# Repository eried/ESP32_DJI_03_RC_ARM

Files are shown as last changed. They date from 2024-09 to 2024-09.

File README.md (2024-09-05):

# ESP32 Arm DJI O3

Code from [here](https://github.com/ramiss/arduino_DJI_03_RC_ARM), this is just slightly adapted for my hardware. This allows enabling the full power on the O3 so you can use it for long range planes or cars. I though with the latest firmware was OK to override via the menu, but without arming it, the power is never the maximum the Air unit can deliver.



## What I am using

There is some minor details mising, like the gopro mount. But that is a personal preference. My idea is just to hook the whole video system to something when I want to drive them.

| Part | Comments |
|---|---|
| [DJI O3 Air Unit](https://s.click.aliexpress.com/e/_DFMCnNp) | The camera
| [1800 mAh Original DJI Goggles 2 Battery](https://www.aliexpress.com/item/1005007042116539.html) | Power bank|
| [Alloy Waterproof Case](https://s.click.aliexpress.com/e/_DlB1UcT) | Enclosure for camera|
| [ESP32 30Pin-Type-C](https://s.click.aliexpress.com/e/_DmRukHz) | Microcontroller board, you have to desolder the pins |
| [JST 6P 1.25 extension](https://s.click.aliexpress.com/e/_DeUX0MT) | For connecting to the case connector |
| [JST 2P 2mm for the battery](https://s.click.aliexpress.com/e/_DC9pJQ7) | Can be any connector/cable |
| [USB-C to barrel](https://s.click.aliexpress.com/e/_DDsXURt) | To connect battery as usb-c |
| [Small switch 3mm handle](https://s.click.aliexpress.com/e/_DlFpkBD) | To enable the Arming |
| Heat shrink, super glue and tape | |
| 33 kOhm and 5.5 kOhm resistors | Optional for sensing the battery, not very interesting in the case of the DJI battery |
| Some translucent glue | For the "led indicators" |
| 3d printer and PLA | For the enclosure |

> [!TIP]  
> To prevent fogging on the camera (O3 gets insanely hot when it is fully armed), DarwinFPV has some instructions of glueing the camera module to the case. I used foam double sided tape. Works OK

## Wiring

The [source repo](https://github.com/ramiss/arduino_DJI_03_RC_ARM) has the wiring. From the DJI connector of the camera, I connected as follows:

| RED | BLACK | YELLOW | GREEN | BLUE | WHITE |
|-----|---|---|---|---|---|
|  VIN (before the switch, so it does not affect the camera) | GND | D17 | D16 | GND | D18 |

> [!NOTE]  
> Since all cables are connected to the ESP32, if something does not work just modify the pins on `Serial1.begin(115200, SERIAL_8N1, 16, 18)`. If O3 is not detected then change the RX pin (16 in this case). If the O3 is detected but not ARMED, change the TX pin (18 in this case).



The voltage divider can be configured in the code in the `map(input, 1475, 1893, 76, 92)`, it is a simplified version of the original, just with a range I am getting from `analogRead(ANALOG_IN)` to the real voltage multiplied for 10. In this example, when `analogRead(ANALOG_IN) == 1475` my multimeter was saying `7.6` volts (`76` in the `map` function).

## Aseembly

The case has holes that align only when the ESP32 was installed with the USB to the left as shown in one of the photos below. 

### Led indicator

The device reports several states with the lights:

State | Red | Blue
--- | --- | ---
 Powered off | OFF  | OFF
 Powered on  | ON | OFF
 Initializing | ON | Very faint (5%)
 Waiting for O3 | ON | Faint (10%)
 ARMING | ON | ON

For the "led indicators" I used some UV activated glue, to try to keep the water out:



Besides this, I used double side tape for the ESP32, glue both cables to the bottom case and the switch in the upper position.



This is how it should look at the end:



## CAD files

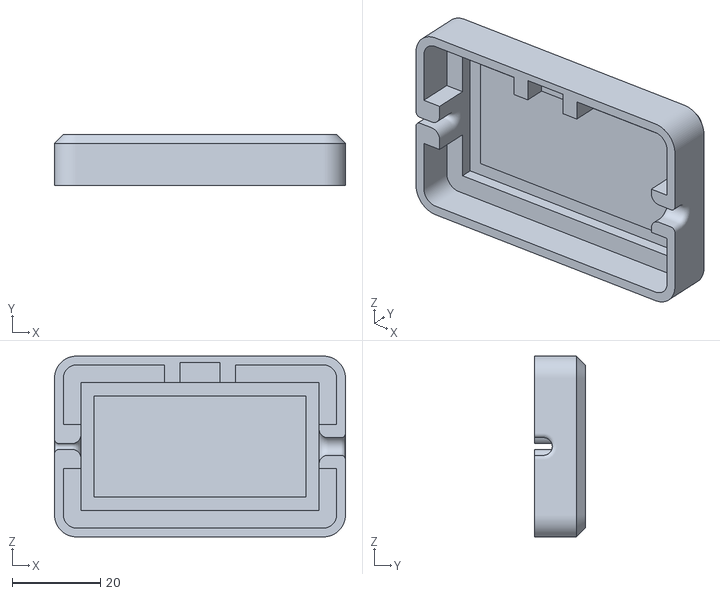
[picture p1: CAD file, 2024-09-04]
case/case_bottom_1.stl
66.0 x 11.5 x 41.0

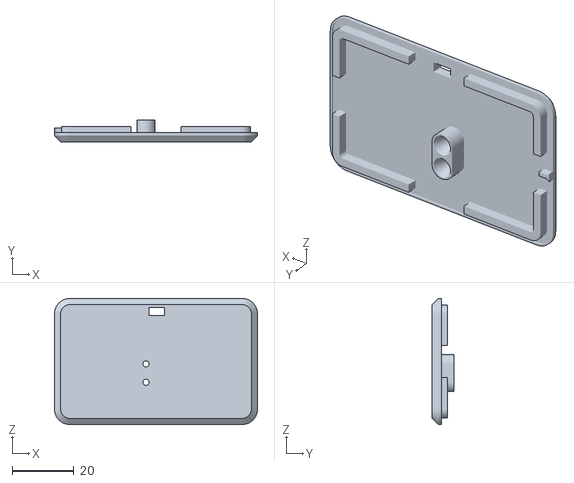
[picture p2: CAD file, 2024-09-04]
case/case_top_2.stl
66.0 x 7.00 x 41.0

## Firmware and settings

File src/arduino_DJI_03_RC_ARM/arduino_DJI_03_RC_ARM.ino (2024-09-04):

/************************************************************************************
  @file       arduino_DJI_03_RC_ARM.ino
  @brief      Send DJI Arm using XIAO Seeeduino over MSP to keep power level at full.
  @author     Richard Amiss
  
  Release Note:  
  Complete rework for XIAO Seeeduino and MSP libraries. RC input is no longer used in 
  this version.  The AU will simply arm a few seconds after being turned on, as long 
  as the goggles are on.
  
  Code:        Richard Amiss
  Version:     1.1.0
  Date:        06/24/23

  Credits:
  This software is based on and uses software published by 2022 David Payne:
  QLiteOSD, which is based on work by Paul Kurucz (pkuruz):opentelem_to_bst_bridge 
  as well as software from d3ngit : djihdfpv_mavlink_to_msp_V2 and 
  crashsalot : VOT_to_DJIFPV

THIS SOFTWARE IS PROVIDED IN AN "AS IS" CONDITION. NO WARRANTIES, WHETHER EXPRESS, 
IMPLIED OR STATUTORY, INCLUDING, BUT NOT LIMITED TO, IMPLIED WARRANTIES OF 
MERCHANTABILITY AND FITNESS FOR A PARTICULAR PURPOSE APPLY TO THIS SOFTWARE. THE 
COMPANY SHALL NOT, IN ANY CIRCUMSTANCES, BE LIABLE FOR SPECIAL, INCIDENTAL OR 
CONSEQUENTIAL DAMAGES, FOR ANY REASON WHATSOEVER.
************************************************************************************/
#include <HardwareSerial.h>


#include "MSP.h"
#include "MSP_OSD.h"
#include "OSD_positions_config.h"

#define ANALOG_IN 4       // Voltage Read pin
#define LED_BUILTIN 2
#define DEBUG  //uncomment to see diagnostics from USB serial

#define FC_FIRMWARE_NAME "Betaflight"
#define FC_FIRMWARE_IDENTIFIER "BTFL"

//HardwareSerial Serial1(2); // use UART2
HardwareSerial &mspSerial = Serial1;
MSP msp;

// Arm Logic
uint32_t unarmedMillis = 3000;  // number of milliseconds to wait before arming, after AU is initialized. Recommend at least 3000 (3 seconds).

//Voltage and Battery Reading
float averageVoltage = 0;
int sampleVoltageCount = 0;
int lastCount = 0;

boolean lightOn = true;

uint8_t *messageID;
void *payload;
uint8_t maxSize;
uint8_t *recvSize;

//Other
char fcVariant[5] = "BTFL";
char craftname[15] = "Craft";
uint32_t previousMillis_MSP = 0;
uint32_t activityDetectedMillis_MSP = 0;
bool activityDetected = false;
const uint32_t next_interval_MSP = 100;
uint32_t general_counter = next_interval_MSP;
uint32_t custom_mode = 0;  //flight mode
uint8_t vbat = 0;
uint32_t flightModeFlags = 0x00000002;
uint8_t batteryCellCount = 3;
uint32_t previousFlightMode = custom_mode;

msp_battery_state_t battery_state = { 0 };
msp_name_t name = { 0 };
msp_fc_version_t fc_version = { 0 };
msp_fc_variant_t fc_variant = { 0 };
//msp_status_BF_t status_BF = {0};
msp_status_DJI_t status_DJI = { 0 };
msp_analog_t analog = { 0 };

void setup() {
#ifdef DEBUG
  Serial.begin(115200);

#endif
  Serial1.begin(115200, SERIAL_8N1, 16, 18); 
  while (!Serial1)
    ;

  msp.begin(mspSerial);
  pinMode(LED_BUILTIN, OUTPUT);
  analogWrite(LED_BUILTIN, 5);

  delay(1000);

  status_DJI.cycleTime = 0x0080;
  status_DJI.i2cErrorCounter = 0;
  status_DJI.sensor = 0x23;
  status_DJI.configProfileIndex = 0;
  status_DJI.averageSystemLoadPercent = 7;
  status_DJI.accCalibrationAxisFlags = 0;
  status_DJI.DJI_ARMING_DISABLE_FLAGS_COUNT = 20;
  status_DJI.djiPackArmingDisabledFlags = (1 << 24);
  flightModeFlags = 0x00000002;

#ifdef DEBUG
  Serial.println("Initialized");
#endif
}

void loop() {


  if (!activityDetected) {
#ifdef DEBUG
    Serial.println("Waiting for AU...");
#endif
    analogWrite(LED_BUILTIN, 10);

    // Wait for Air Unit to send data
    while (!msp.activityDetected()) {
    };
    activityDetected = true;
    activityDetectedMillis_MSP = millis();
#ifdef DEBUG
    Serial.println("AU Detected, waiting (unarmedMillis) time till arm");
#endif
  }

  analogWrite(LED_BUILTIN, 255);

  uint32_t currentMillis_MSP = millis();

  if ((uint32_t)(currentMillis_MSP - previousMillis_MSP) >= next_interval_MSP) {
    previousMillis_MSP = currentMillis_MSP;

    if (general_counter % 300 == 0) {  // update the altitude and voltage values every 300ms
      getVoltageSample();
      if (lightOn) {
        analogWrite(LED_BUILTIN, 0);
      } else {
        analogWrite(LED_BUILTIN, 255);
      }
      lightOn = !lightOn;
    }

    if (currentMillis_MSP < (activityDetectedMillis_MSP + unarmedMillis)) {
      set_flight_mode_flags(false);
    } else {
      set_flight_mode_flags(true);
    }

#ifdef DEBUG
    debugPrint();
#endif
    send_msp_to_airunit();
    general_counter += next_interval_MSP;
  }
  if (custom_mode != previousFlightMode) {
    previousFlightMode = custom_mode;
    display_flight_mode();
  }

  if (batteryCellCount == 0 && vbat > 0) {
    set_battery_cells_number();
  }

  //display flight mode every 10s
  if (general_counter % 10000 == 0) {
    display_flight_mode();
  }
}

msp_osd_config_t msp_osd_config = { 0 };

void send_osd_config() {

#ifdef IMPERIAL_UNITS
  msp_osd_config.units = 0;
#else
  msp_osd_config.units = 1;
#endif

  msp_osd_config.osd_item_count = 56;
  msp_osd_config.osd_stat_count = 24;
  msp_osd_config.osd_timer_count = 2;
  msp_osd_config.osd_warning_count = 16;  // 16
  msp_osd_config.osd_profile_count = 1;   // 1
  msp_osd_config.osdprofileindex = 1;     // 1
  msp_osd_config.overlay_radio_mode = 0;  //  0

  msp_osd_config.osd_rssi_value_pos = osd_rssi_value_pos;
  msp_osd_config.osd_main_batt_voltage_pos = osd_main_batt_voltage_pos;
  msp_osd_config.osd_crosshairs_pos = osd_crosshairs_pos;
  msp_osd_config.osd_artificial_horizon_pos = osd_artificial_horizon_pos;
  msp_osd_config.osd_horizon_sidebars_pos = osd_horizon_sidebars_pos;
  msp_osd_config.osd_item_timer_1_pos = osd_item_timer_1_pos;
  msp_osd_config.osd_item_timer_2_pos = osd_item_timer_2_pos;
  msp_osd_config.osd_flymode_pos = osd_flymode_pos;
  msp_osd_config.osd_craft_name_pos = osd_craft_name_pos;
  msp_osd_config.osd_throttle_pos_pos = osd_throttle_pos_pos;
  msp_osd_config.osd_vtx_channel_pos = osd_vtx_channel_pos;
  msp_osd_config.osd_current_draw_pos = osd_current_draw_pos;
  msp_osd_config.osd_mah_drawn_pos = osd_mah_drawn_pos;
  msp_osd_config.osd_gps_speed_pos = osd_gps_speed_pos;
  msp_osd_config.osd_gps_sats_pos = osd_gps_sats_pos;
  msp_osd_config.osd_altitude_pos = osd_altitude_pos;
  msp_osd_config.osd_roll_pids_pos = osd_roll_pids_pos;
  msp_osd_config.osd_pitch_pids_pos = osd_pitch_pids_pos;
  msp_osd_config.osd_yaw_pids_pos = osd_yaw_pids_pos;
  msp_osd_config.osd_power_pos = osd_power_pos;
  msp_osd_config.osd_pidrate_profile_pos = osd_pidrate_profile_pos;
  msp_osd_config.osd_warnings_pos = osd_warnings_pos;
  msp_osd_config.osd_avg_cell_voltage_pos = osd_avg_cell_voltage_pos;
  msp_osd_config.osd_gps_lon_pos = osd_gps_lon_pos;
  msp_osd_config.osd_gps_lat_pos = osd_gps_lat_pos;
  msp_osd_config.osd_debug_pos = osd_debug_pos;
  msp_osd_config.osd_pitch_angle_pos = osd_pitch_angle_pos;
  msp_osd_config.osd_roll_angle_pos = osd_roll_angle_pos;
  msp_osd_config.osd_main_batt_usage_pos = osd_main_batt_usage_pos;
  msp_osd_config.osd_disarmed_pos = osd_disarmed_pos;
  msp_osd_config.osd_home_dir_pos = osd_home_dir_pos;
  msp_osd_config.osd_home_dist_pos = osd_home_dist_pos;
  msp_osd_config.osd_numerical_heading_pos = osd_numerical_heading_pos;
  msp_osd_config.osd_numerical_vario_pos = osd_numerical_vario_pos;
  msp_osd_config.osd_compass_bar_pos = osd_compass_bar_pos;
  msp_osd_config.osd_esc_tmp_pos = osd_esc_tmp_pos;
  msp_osd_config.osd_esc_rpm_pos = osd_esc_rpm_pos;
  msp_osd_config.osd_remaining_time_estimate_pos = osd_remaining_time_estimate_pos;
  msp_osd_config.osd_rtc_datetime_pos = osd_rtc_datetime_pos;
  msp_osd_config.osd_adjustment_range_pos = osd_adjustment_range_pos;
  msp_osd_config.osd_core_temperature_pos = osd_core_temperature_pos;
  msp_osd_config.osd_anti_gravity_pos = osd_anti_gravity_pos;
  msp_osd_config.osd_g_force_pos = osd_g_force_pos;
  msp_osd_config.osd_motor_diag_pos = osd_motor_diag_pos;
  msp_osd_config.osd_log_status_pos = osd_log_status_pos;
  msp_osd_config.osd_flip_arrow_pos = osd_flip_arrow_pos;
  msp_osd_config.osd_link_quality_pos = osd_link_quality_pos;
  msp_osd_config.osd_flight_dist_pos = osd_flight_dist_pos;
  msp_osd_config.osd_stick_overlay_left_pos = osd_stick_overlay_left_pos;
  msp_osd_config.osd_stick_overlay_right_pos = osd_stick_overlay_right_pos;
  msp_osd_config.osd_display_name_pos = osd_display_name_pos;
  msp_osd_config.osd_esc_rpm_freq_pos = osd_esc_rpm_freq_pos;
  msp_osd_config.osd_rate_profile_name_pos = osd_rate_profile_name_pos;
  msp_osd_config.osd_pid_profile_name_pos = osd_pid_profile_name_pos;
  msp_osd_config.osd_profile_name_pos = osd_profile_name_pos;
  msp_osd_config.osd_rssi_dbm_value_pos = osd_rssi_dbm_value_pos;
  msp_osd_config.osd_rc_channels_pos = osd_rc_channels_pos;

  msp.send(MSP_OSD_CONFIG, &msp_osd_config, sizeof(msp_osd_config));
}


void invert_pos(uint16_t *pos1, uint16_t *pos2) {
  uint16_t tmp_pos = *pos1;
  *pos1 = *pos2;
  *pos2 = tmp_pos;
}

void set_flight_mode_flags(bool arm) {
  if ((flightModeFlags == 0x00000002) && arm) {
    flightModeFlags = 0x00000003;  // arm
#ifdef DEBUG
    Serial.println("ARMING");
#endif
  } else if ((flightModeFlags == 0x00000003) && !arm) {
    flightModeFlags = 0x00000002;  // disarm
#ifdef DEBUG
    Serial.println("DISARMING");
#endif
  }
}

void display_flight_mode() {
  show_text(&craftname);
}

void send_msp_to_airunit() {

  //MSP_FC_VARIANT
  memcpy(fc_variant.flightControlIdentifier, fcVariant, sizeof(fcVariant));
  msp.send(MSP_FC_VARIANT, &fc_variant, sizeof(fc_variant));

  //MSP_FC_VERSION
  fc_version.versionMajor = 4;
  fc_version.versionMinor = 1;
  fc_version.versionPatchLevel = 1;
  msp.send(MSP_FC_VERSION, &fc_version, sizeof(fc_version));

  //MSP_NAME
  memcpy(name.craft_name, craftname, sizeof(craftname));
  msp.send(MSP_NAME, &name, sizeof(name));

  //MSP_STATUS
  status_DJI.flightModeFlags = flightModeFlags;
  status_DJI.armingFlags = 0x0303;
  msp.send(MSP_STATUS_EX, &status_DJI, sizeof(status_DJI));
  status_DJI.armingFlags = 0x0000;
  msp.send(MSP_STATUS, &status_DJI, sizeof(status_DJI));

  //MSP_BATTERY_STATE
  battery_state.amperage = 0;
  battery_state.batteryVoltage = vbat * 10;
  battery_state.mAhDrawn = 0;
  battery_state.batteryCellCount = batteryCellCount;
  battery_state.batteryCapacity = 0;
  battery_state.batteryState = 0;
  battery_state.legacyBatteryVoltage = vbat;
  msp.send(MSP_BATTERY_STATE, &battery_state, sizeof(battery_state));

  //MSP_OSD_CONFIG
  send_osd_config();
}

void show_text(char (*text)[15]) {
  memcpy(craftname, *text, sizeof(craftname));
}

void set_battery_cells_number() {
  if (vbat < 43) batteryCellCount = 1;
  else if (vbat < 85) batteryCellCount = 2;
  else if (vbat < 127) batteryCellCount = 3;
  else if (vbat < 169) batteryCellCount = 4;
  else if (vbat < 211) batteryCellCount = 5;
  else if (vbat < 255) batteryCellCount = 6;
}



void getVoltageSample() {
  vbat = map(analogRead(ANALOG_IN), 1475, 1893, 76, 92);
}

//*** USED ONLY FOR DEBUG ***
void debugPrint() {
  Serial.println("**********************************");
  Serial.print("Flight Mode: ");
  Serial.println(flightModeFlags);
  Serial.print("Voltage: ");
  Serial.println(((double)vbat / 10), 1);
  Serial.print("Sample Count / transmit: ");
  Serial.println(lastCount);
  Serial.print("Battery Cell Count: ");
  Serial.println(batteryCellCount);
}

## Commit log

2024-09-04 Add the printed case
    [case_bottom_1.stl, case_top_2.stl]
2024-09-04 Adapting to ESP32 WROOM-32
